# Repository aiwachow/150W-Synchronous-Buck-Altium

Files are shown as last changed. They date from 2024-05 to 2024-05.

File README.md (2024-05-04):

# 150W POWER SUPPLY 
Power supply based on LM5146 synchronous buck controller [lm5146.pdf](https://github.com/aiwachow/150W-Synchronous-Buck/files/15058466/lm5146.pdf) 9.2.2 Design 2
. <br />
PCB layout based on [snva803.pdf](https://github.com/aiwachow/150W-Synchronous-Buck/files/15058517/snva803.pdf) section: Extension to High-Current Applications

**Designed for roboticists scientific association project purpose.** <br />

Electrical characteristics and parameters: 
- 400KHz switching freq.
- 12V output voltage* (Important note in Testing) 
- Full load current of 15A
- Input voltage of 15V to 85V
- ...

BuckSchematic-1

## Used tools: 
altiumLOGOwebench-power-designer-logo

## Testing
**Warning!** PCB has been manufactured, assembled and tested. Due to lack of choosen inductor at the distributor, tests were made with unsuitable one, for this reason, the inductor enters pulse mode and buck gives not 12V but 7V on the output. 
However, no other errors were detected so finall test will be carried out when new inductor arrive.  <br /> **In addition, pcb and gerber files will be made available when the power supply is 100% working**

buck

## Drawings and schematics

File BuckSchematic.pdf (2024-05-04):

# SWITCHING REGULATOR MODULE

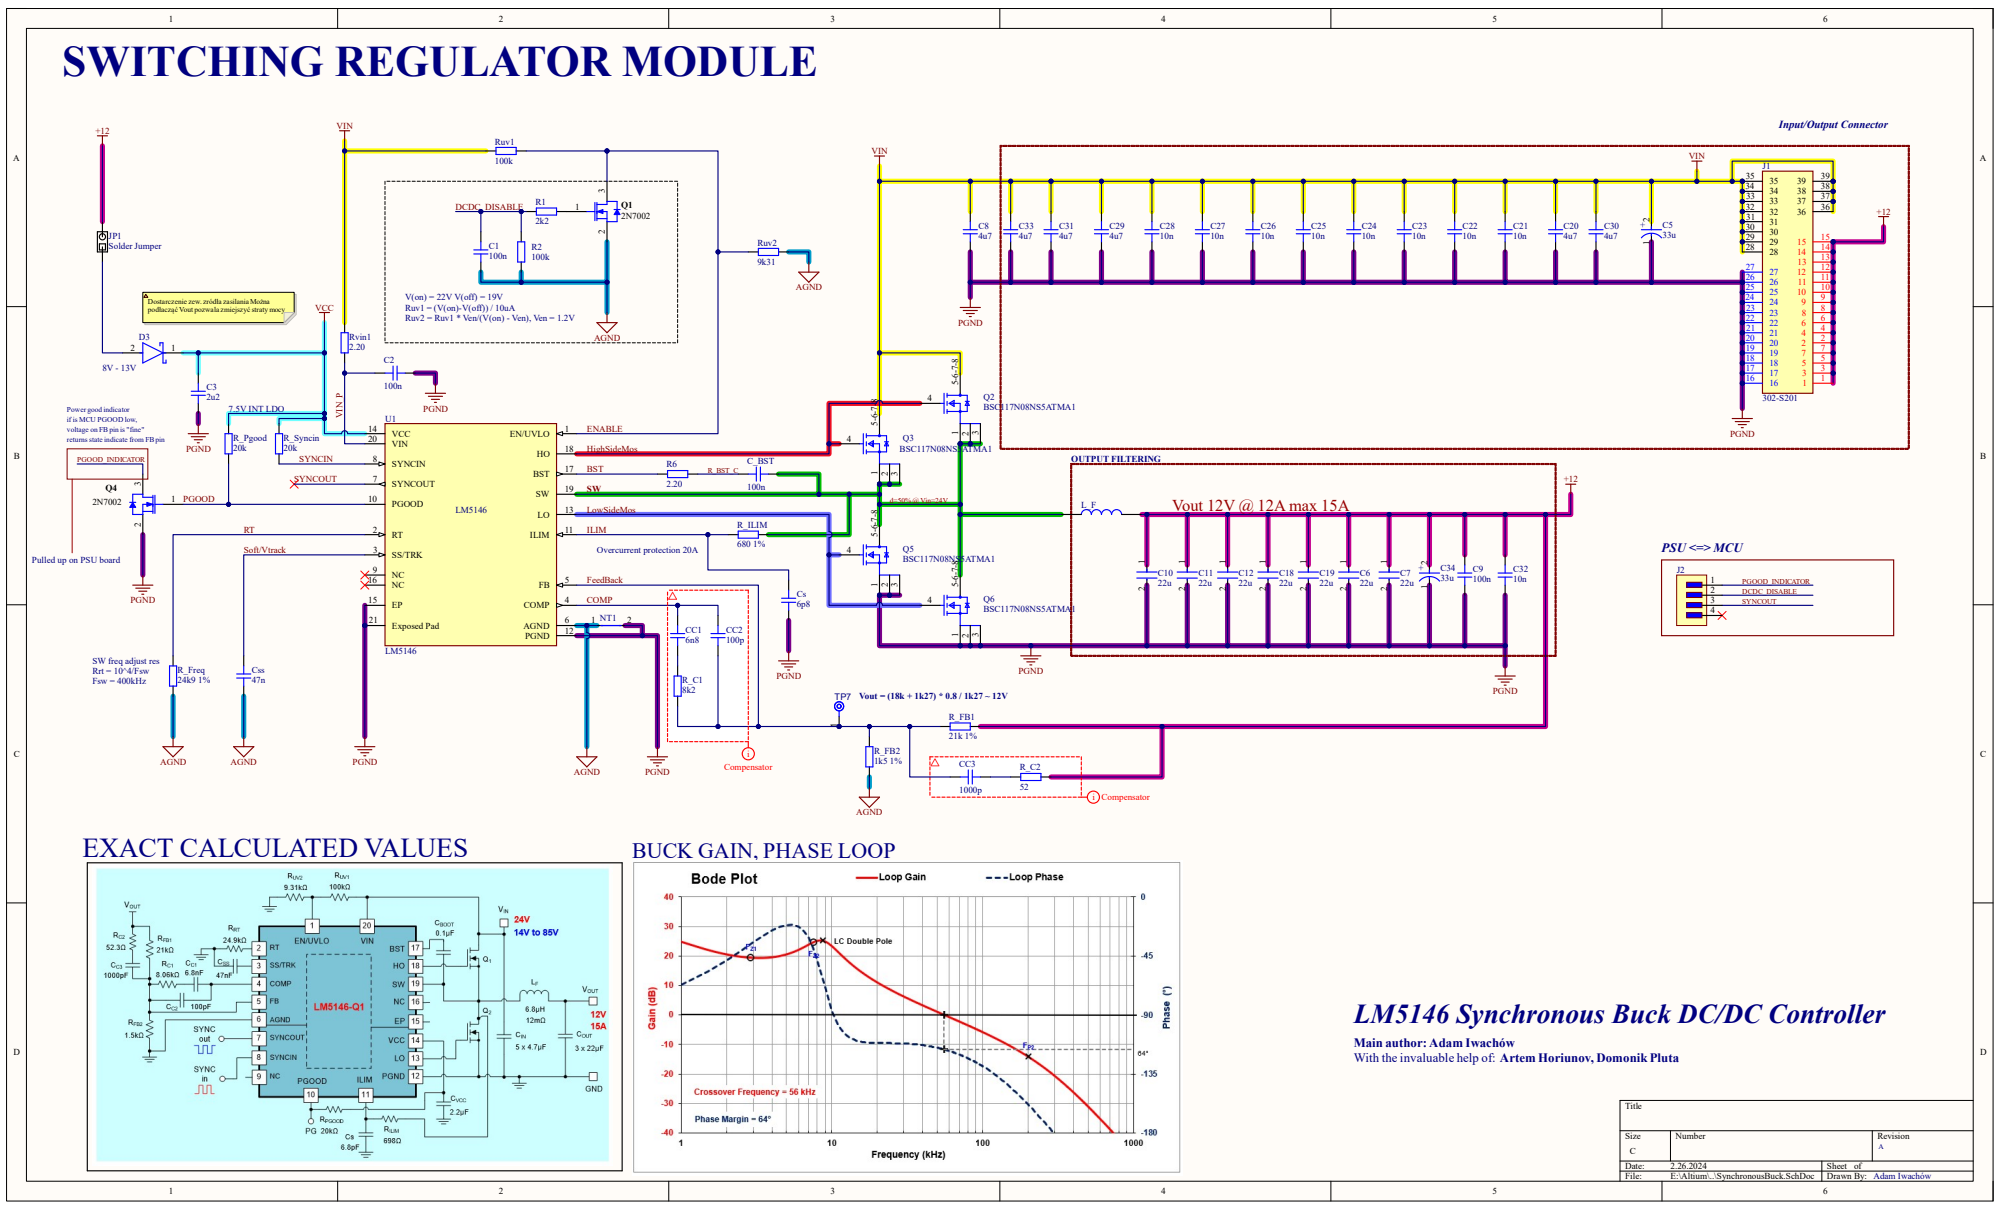
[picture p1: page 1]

Dostarczenie zew. zródła zasilania Można
podłacząć Vout pozwala zmiejszyć straty mocy

V(on) = 22V V(off) = 19V
Ruv1 = (V(on)-V(off)) / 10uA
Ruv2 = Ruv1 * Ven/(V(on) - Ven), Ven = 1.2V

Power good indicator
if is MCU PGOOD low,
voltage on FB pin is "fine"3
returns state indicate from FB pin

Pulled up on PSU board

SW freq adjust res
Rrt = 10^4/Fsw
Fsw = 400kHz

BUCK GAIN, PHASE LOOP

LM5146 Synchronous Buck DC/DC Controller

Main author: Adam Iwachów
With the invaluable help of:

Artem Horiunov, Domonik Pluta
